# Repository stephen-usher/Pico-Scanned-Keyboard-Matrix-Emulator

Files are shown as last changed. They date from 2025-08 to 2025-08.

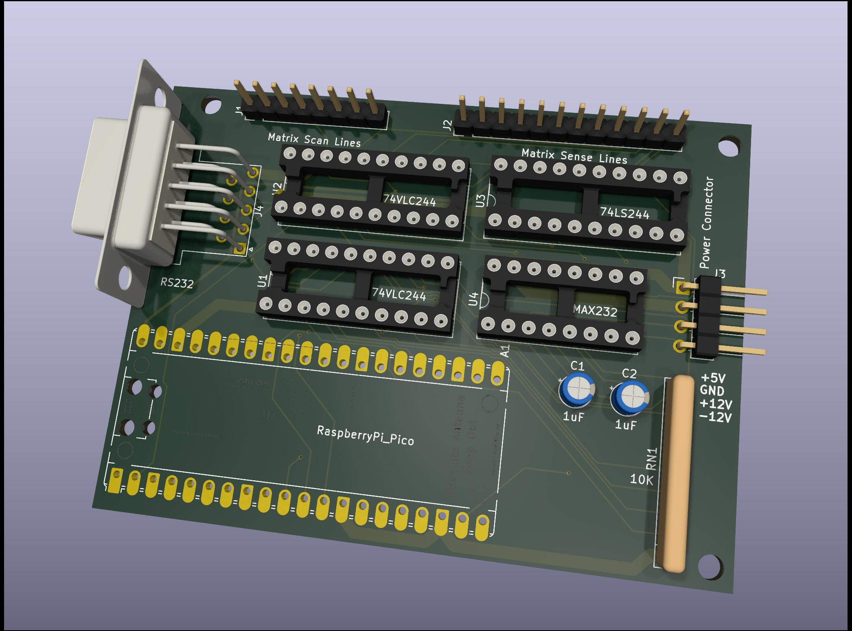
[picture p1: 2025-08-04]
Pico-Keyboard-Matrix-Interface.jpg

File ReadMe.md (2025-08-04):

This is a generic scanned keyboard matrix emulation board based upon a Raspberry Pi Pico.

It supports any scanned keyboard matrix which has up to 8 scan lines (outputs from the computer) and 12 sense lines (inputs to the computer).

The board itself is really just a Pico interface board with 8 TTL compatible inputs to the GPIO and 12 TTL compatible outputs with an RS232 compatible interface to the default UART. The 8 and 12 pin ports are contiguous ranges on the Pico allowing PIO operations as a bus. All the keyboard matrix magic happens in software. It's using 74LVC244 chips to act as step-down voltage converted on the input and the 74LS244 as a step-up on the output.

The initial firmware supports the Sinclair QL but I will later probably add the Memotech MTX Series and maybe ZX Spectrum and ZX81.

To use the board with a USB keyboard you will need to add a USB OTG (On The Go) adapter cable and set the Pico SDK to use the serial port for stdio so as to use the TinyUSB library.

Note: Because I didn't realise that the Pico doesn't drive the VBUS power line when powered from the VSYS line a bodge wire will be needed to bridge between the two pins on the Pico otherwise the output 74LS244 doesn't get power.

Note 2: If you only need 8 sense lines (such as for the Sinclair QL) and you don't need the RS232 port then you only need to install U1 and U3 buffer chips and not U2 (74VLC244) or U4 (MAX232) you also don't need to fit the DB9 socket or the two electrolytic caps. In this minimal configuration you only need +5V and GND to power the board.

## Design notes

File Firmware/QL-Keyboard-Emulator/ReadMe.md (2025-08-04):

This is the Pico firmware to emulate a QL keyboard matrix.

This can either be used via a serial connection or, with the addition of a USB OTG (On The Go) cable, a USB keyboard.

For the USB keyboard the code can be configured for either a UK keyboard or a US one. For other languages a rather more radical redefinition of shifted keys would be required and possibly the addition of more USB keycodes to the table.

It should be noted that if the board is only going to be used with a QL and only with a USB keyboard then the second 74VLC244 and all the serial port parts (MAX232, capacitors and DB9 port) can be omitted from the PCB and only 5V and GND power is required.

You will need to replace the two keyboard ribbon cable sockets (J11 and J12) on the QL motherboard with pin headers. Run two 8 way ribbon cables with Dupont connectors on the end from the two connectors on this board to the motherboard. The left (scan lines) plug into pins 1 to 8 of J11, pin 1 goes to pin 1. The right (sense lines) go from pin 3 to pin 10 of J12, pin 1 on this board connects to pin 3 on J12 etc.

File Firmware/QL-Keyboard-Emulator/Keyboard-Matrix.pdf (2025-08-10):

QL Keyboard Matrix

J12
| 1 | 2 | 3 (1) | 4 (2) | 5 (3) | 6 (4) | 7 (5) | 8 (6) | 9 (7) | 10 (8) | 11
1 | | | F1 | F2 | F3 | 4 | 5 | 7 | F4 | F5
2 | | | 2 | q | e | t | 6 | u | 8 | 0
3 | | | w | TAB | r | y | i | o | 9 | -
4 | | | 3 | 1 | a | d | h | j | l | p
J11 | 5 | CAPS | s | f | g | k | ; | [ | =
6 | | | z | c | b | m | . | ' | ] | `
7 | | | CTRL | x | v | n | ALT | , | SHIFT | /
8 | | | ← | ESC | → | Space | ↑ | ↓ | Return | \
9 | CTRL | SHIFT | | | | | | | | | ALT
Note: | J12 pins 1,2 and 11 are actually connected to pins 1, 7 and 5 through diodes and hence scan there.
| Similarly J11 pin 9 is connected to pin 7 via a diode and is scanned there.

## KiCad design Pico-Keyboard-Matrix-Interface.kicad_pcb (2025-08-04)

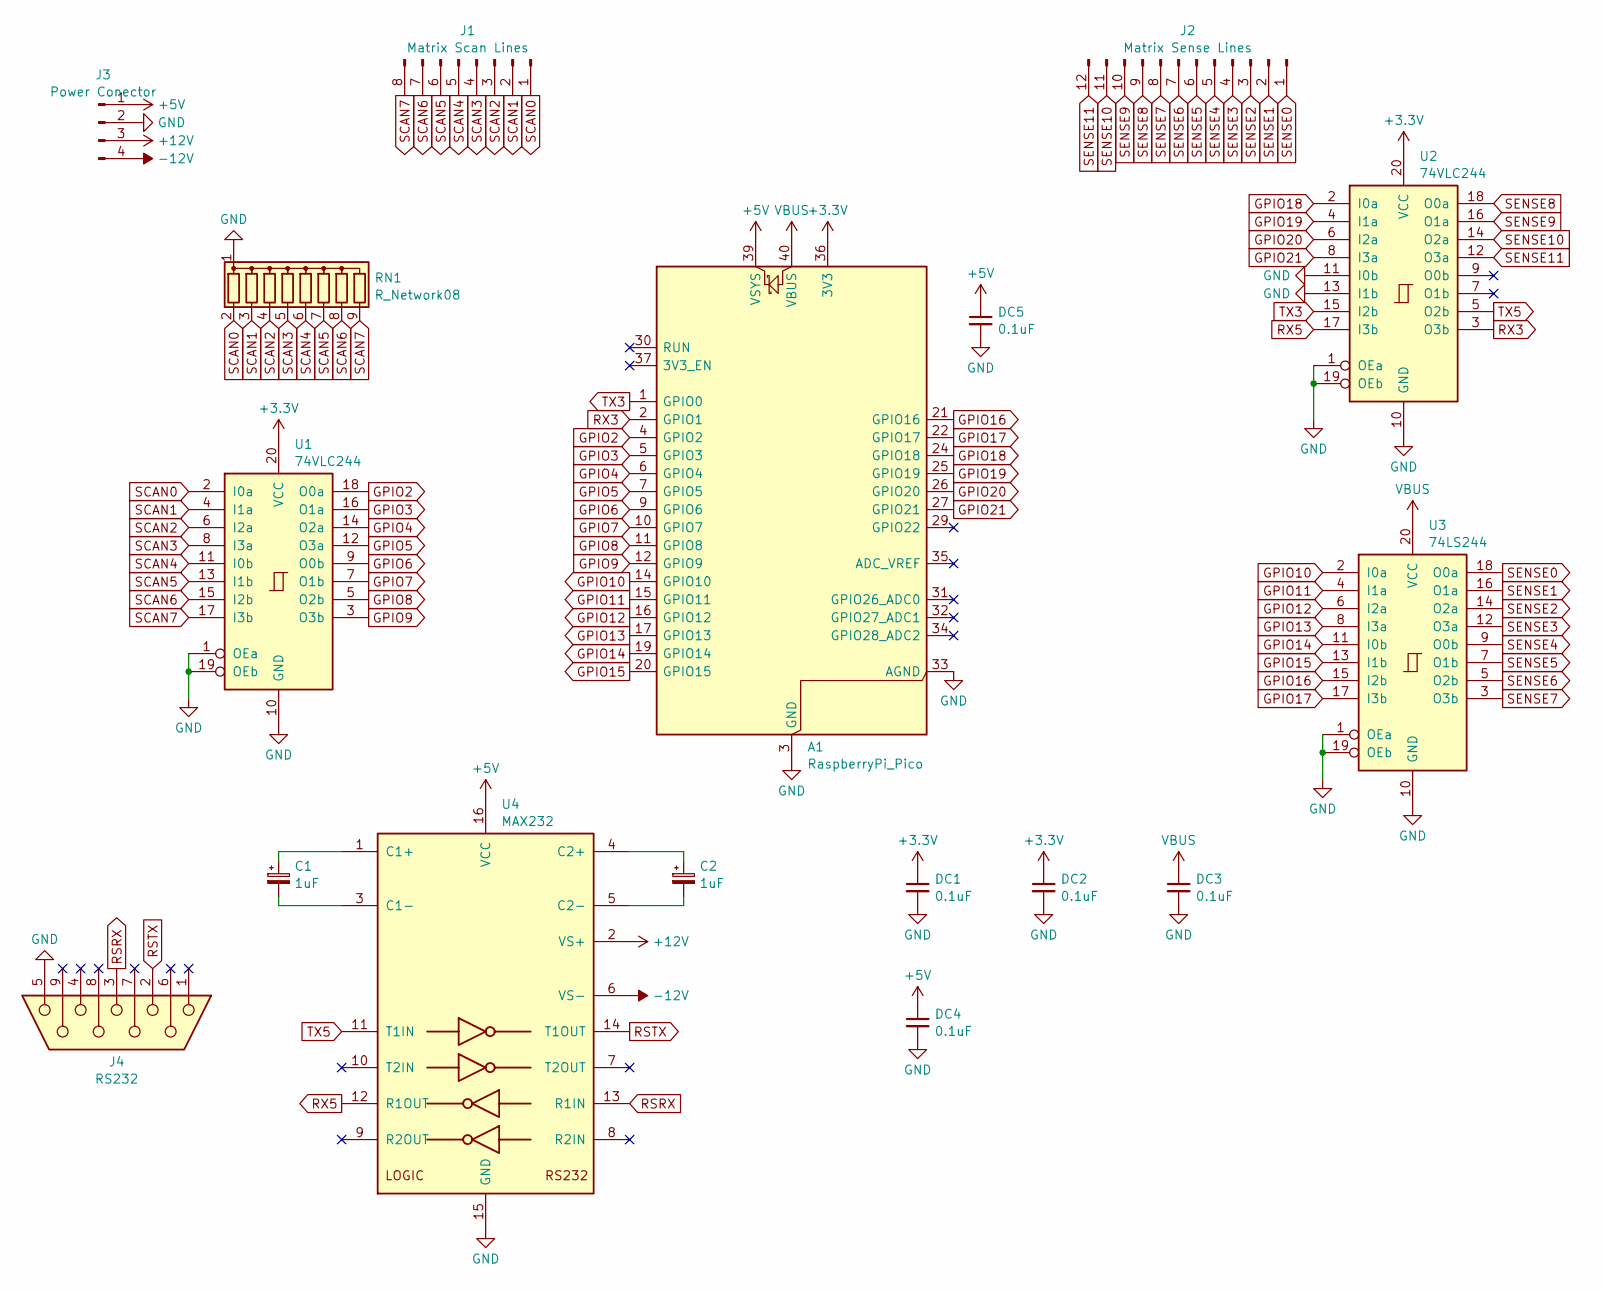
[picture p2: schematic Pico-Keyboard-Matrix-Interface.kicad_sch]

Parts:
A1: RaspberryPi_Pico; RaspberryPi_Pico_Common_Unspecified
C1, C2: 1uF; CP_Radial_D4.0mm_P2.00mm
DC1, DC2, DC3, DC4, DC5: 0.1uF; C_0805_2012Metric_Pad1.18x1.45mm_HandSolder
J1: Matrix Scan Lines; PinHeader_1x08_P2.54mm_Vertical
J2: Matrix Sense Lines; PinHeader_1x12_P2.54mm_Vertical
J3: Power Conector; PinHeader_1x04_P2.54mm_Horizontal
J4: RS232; DSUB-9_Socket_Horizontal_P2.77x2.84mm_EdgePinOffset9.40mm
RN1: R_Network08; R_Array_SIP9
U1, U2: 74VLC244; DIP-20_W7.62mm_Socket
U3: 74LS244; DIP-20_W7.62mm_Socket
U4: MAX232; DIP-16_W7.62mm_Socket

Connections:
+3.3V: A1.36 (3V3), DC1.1, DC2.1, U1.20 (VCC), U2.20 (VCC)
+5V: A1.39 (VSYS), DC4.1, DC5.1, J3.1, U4.16 (VCC)
+12V: J3.3, U4.2 (VS+)
-12V: J3.4, U4.6 (VS-)
GND: A1.3 (GND), A1.8 (GND), A1.13 (GND), A1.18 (GND), A1.23 (GND), A1.28 (GND), A1.33 (AGND), A1.38 (GND), DC1.2, DC2.2, DC3.2, DC4.2, DC5.2, J3.2, J4.5, RN1.1 (common), U1.1 (OEa), U1.10 (GND), U1.19 (OEb), U2.1 (OEa), U2.10 (GND), U2.11 (I0b), U2.13 (I1b), U2.19 (OEb), U3.1 (OEa), U3.10 (GND), U3.19 (OEb), U4.15 (GND)
GPIO2: A1.4 (GPIO2), U1.18 (O0a)
GPIO3: A1.5 (GPIO3), U1.16 (O1a)
GPIO4: A1.6 (GPIO4), U1.14 (O2a)
GPIO5: A1.7 (GPIO5), U1.12 (O3a)
GPIO6: A1.9 (GPIO6), U1.9 (O0b)
GPIO7: A1.10 (GPIO7), U1.7 (O1b)
GPIO8: A1.11 (GPIO8), U1.5 (O2b)
GPIO9: A1.12 (GPIO9), U1.3 (O3b)
GPIO10: A1.14 (GPIO10), U3.2 (I0a)
GPIO11: A1.15 (GPIO11), U3.4 (I1a)
GPIO12: A1.16 (GPIO12), U3.6 (I2a)
GPIO13: A1.17 (GPIO13), U3.8 (I3a)
GPIO14: A1.19 (GPIO14), U3.11 (I0b)
GPIO15: A1.20 (GPIO15), U3.13 (I1b)
GPIO16: A1.21 (GPIO16), U3.15 (I2b)
GPIO17: A1.22 (GPIO17), U3.17 (I3b)
GPIO18: A1.24 (GPIO18), U2.2 (I0a)
GPIO19: A1.25 (GPIO19), U2.4 (I1a)
GPIO20: A1.26 (GPIO20), U2.6 (I2a)
GPIO21: A1.27 (GPIO21), U2.8 (I3a)
unnamed: C1.1, U4.1 (C1+)
unnamed: C1.2, U4.3 (C1-)
unnamed: C2.1, U4.4 (C2+)
unnamed: C2.2, U4.5 (C2-)
RSRX: J4.3, U4.13 (R1IN)
RSTX: J4.2, U4.14 (T1OUT)
RX3: A1.2 (GPIO1), U2.3 (O3b)
RX5: U2.17 (I3b), U4.12 (R1OUT)
SCAN0: J1.1, RN1.2 (R1), U1.2 (I0a)
SCAN1: J1.2, RN1.3 (R2), U1.4 (I1a)
SCAN2: J1.3, RN1.4 (R3), U1.6 (I2a)
SCAN3: J1.4, RN1.5 (R4), U1.8 (I3a)
SCAN4: J1.5, RN1.6 (R5), U1.11 (I0b)
SCAN5: J1.6, RN1.7 (R6), U1.13 (I1b)
SCAN6: J1.7, RN1.8 (R7), U1.15 (I2b)
SCAN7: J1.8, RN1.9 (R8), U1.17 (I3b)
SENSE0: J2.1, U3.18 (O0a)
SENSE1: J2.2, U3.16 (O1a)
SENSE2: J2.3, U3.14 (O2a)
SENSE3: J2.4, U3.12 (O3a)
SENSE4: J2.5, U3.9 (O0b)
SENSE5: J2.6, U3.7 (O1b)
SENSE6: J2.7, U3.5 (O2b)
SENSE7: J2.8, U3.3 (O3b)
SENSE8: J2.9, U2.18 (O0a)
SENSE9: J2.10, U2.16 (O1a)
SENSE10: J2.11, U2.14 (O2a)
SENSE11: J2.12, U2.12 (O3a)
TX3: A1.1 (GPIO0), U2.15 (I2b)
TX5: U2.5 (O2b), U4.11 (T1IN)
VBUS: A1.40 (VBUS), DC3.1, U3.20 (VCC)

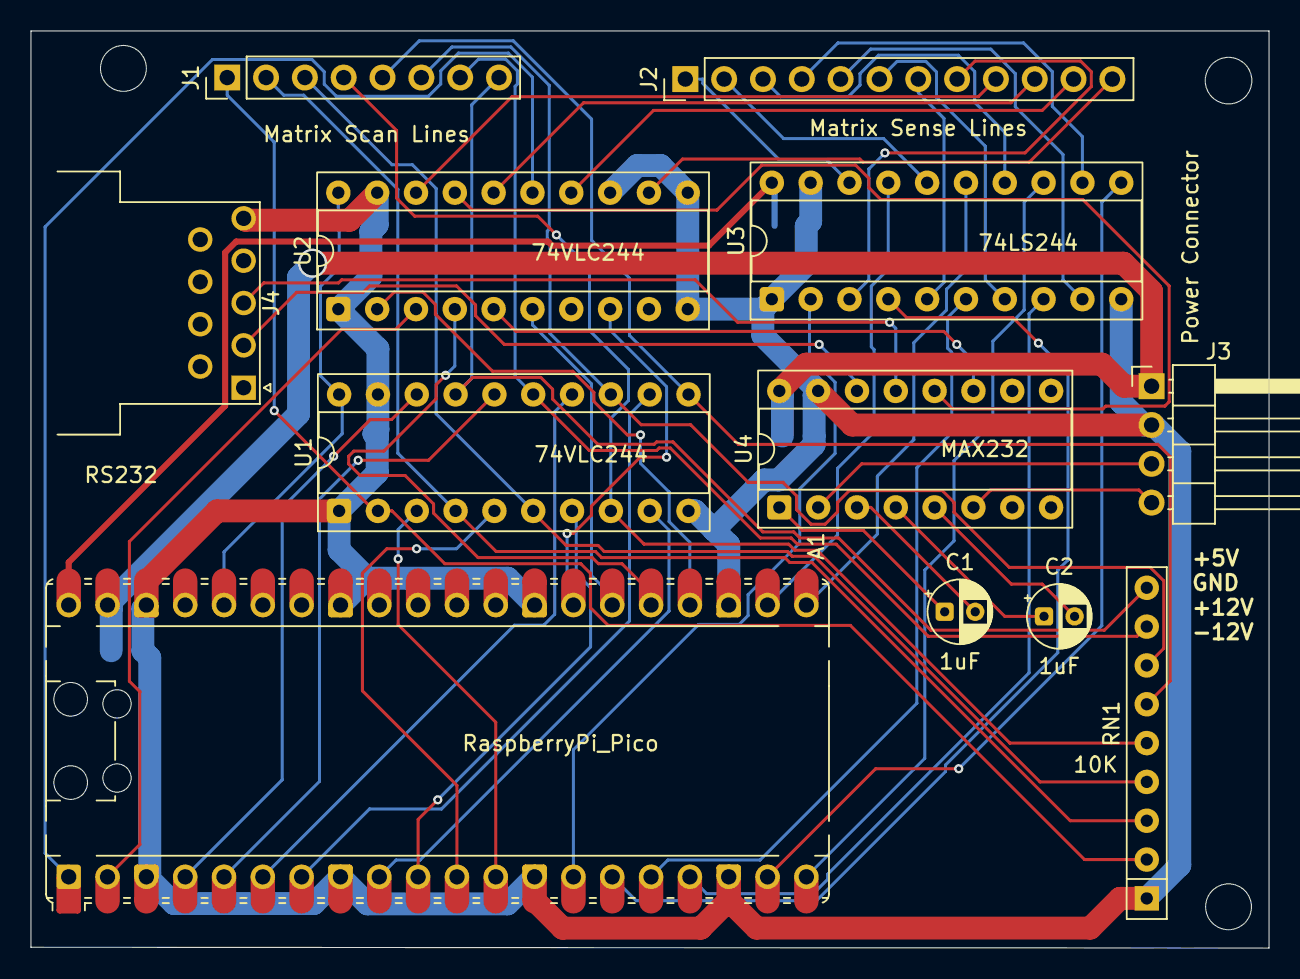
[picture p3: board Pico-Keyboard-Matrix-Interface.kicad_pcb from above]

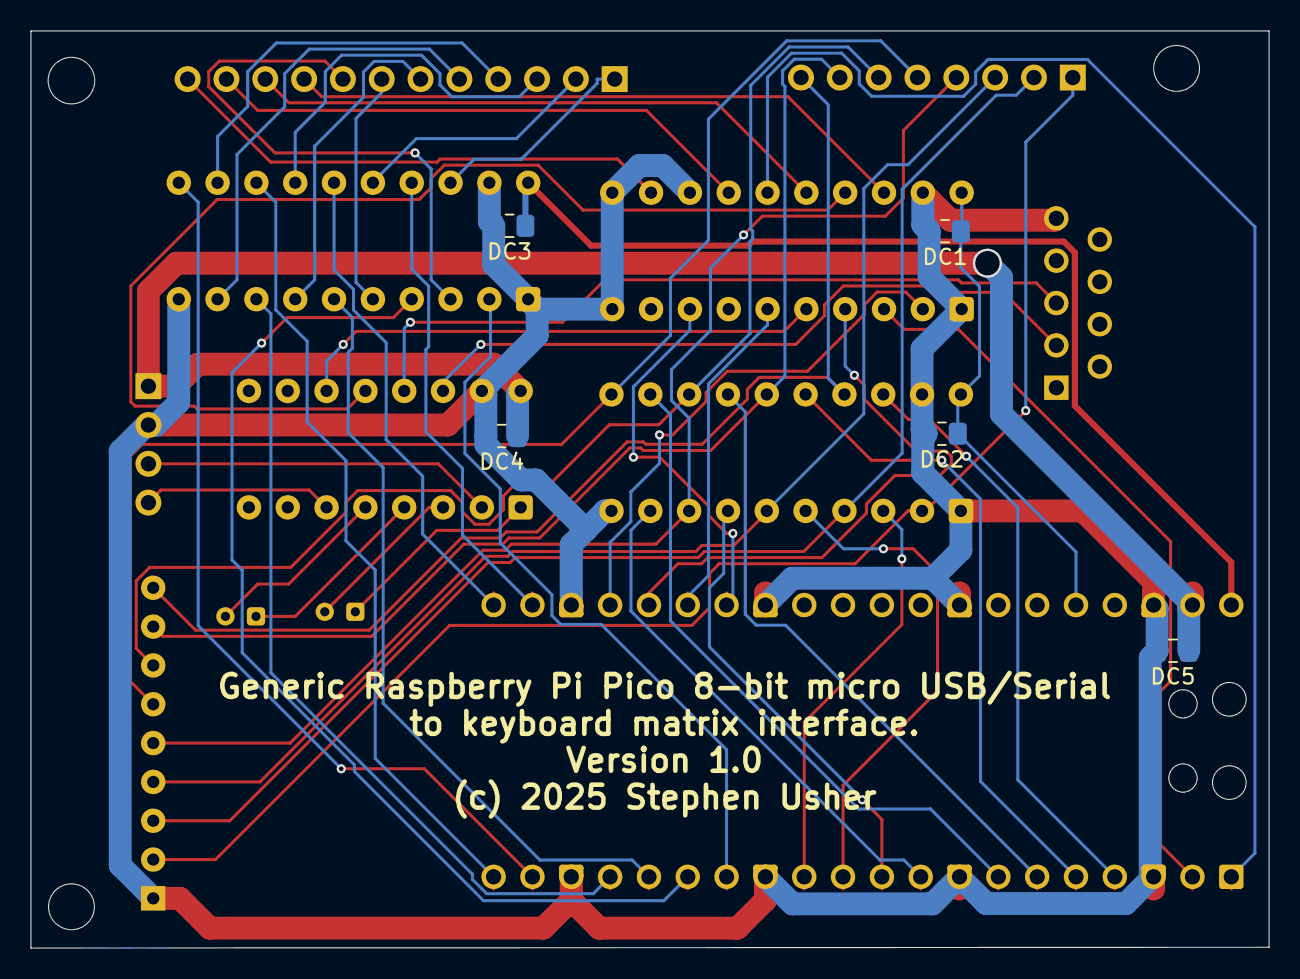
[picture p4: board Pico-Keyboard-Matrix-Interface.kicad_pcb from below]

Board: 2 copper layers, 81.0 x 60.0 mm, 17 parts (5 on the bottom side), 56 nets.

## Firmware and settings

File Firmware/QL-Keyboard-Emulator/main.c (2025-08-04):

#include <stdio.h>
#include "pico/stdlib.h"
#include "hardware/pio.h"
#include "pico/multicore.h"

#include "qlkeyboard.h"

#include "qlkeydecode.h"

unsigned char qlcodes[8] = {0, 0, 0, 0, 0, 0, 0, 0};
unsigned int codereadsem = 0;

int main()
{
	stdio_init_all();

	multicore_launch_core1(bus_io_handler);

	input_read_process();
}

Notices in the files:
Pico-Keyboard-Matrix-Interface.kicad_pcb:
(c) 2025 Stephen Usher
